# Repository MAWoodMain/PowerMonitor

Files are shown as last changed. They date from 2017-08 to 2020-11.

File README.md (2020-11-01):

# PowerMonitor
This is a tool for monitoring household electrical power using multi-channel  clamp based hardware, it defaults to monitoring at a 1 second rate. Although it could run faster than this, it hasn't been tested at higher rates.

The orignal concept was to make energy disagregation easier by providing a capability to monitor the main meter feed to a house, and all of the individual circuits. So the hardware allows for one 100 Amp current clamp (with burden resitor on the board), and 8 other clamps without burden resistors for use with lower power clamps which include thier own burden resistors. Currently only the main meter feed (whole house) is being used, but the other circuits do operate (with appropriate configuration), but haven't been exaustively tested. 

## Software
The software has been developed in Java. Java language level 8 is used because of limited availability of a Java run time for the RPI Zero W above 8. Originally the software was developed to use an API interface for updating a database, but all of the more recent deveopment has focused on using an MQTT interface with JSON encoded messages. This is to fit in with the MING stack (MQTT, Influx, Node-RED, Grafana) for transmitting, storing processing and displaying the data.

## Firmware
The firmware written in C is based on that produced by the [EmonPi project](https://github.com/openenergymonitor/emonpi) but has been modified to read multiple circuits, and operates with a shorter cycle time to help with disgregation. As such it needs a A/C to A/C transofrmer to provide a waveform plus a power supply for the RPi

## Hardware
The hardware was developed by [Matt Wood](https://github.com/MAWoodMain) at an early stage of his experimentation with hardware, from my perspective it does a fine job, but he now sees ways it can be done better. Future improvements may include noise reduction and higher accuracy.

## Metrics
The following Metrics are collected
### Basic Metrics
  1. Voltage (Volts)
  2. Current (Amps)
### Power Metrics (calculated from basic metrics)
  1. Real Power (Watts)
  2. Apparent Power (VA - Volt Amps)
  3. Reactive Power (VAR - Volt Amps Reactive)
  4. Power Factor (Real / Apparent)
### Energy Metrics (calculated from power metrics)
  1. Energy over accumulation interval (Watt Hours)
  2. Cumulative Energy today (Kilowatt Hours)

## Current Release
The current release 0.3-alpha has the following improvements over the last release
### Code Structure
  * The code has been fundamentally restructured to allow for commands to alter data, enums have been replaced by classes.
  * The command processor and associated supporting classes have been added
  * All commands and responses are now sent using JSON rather than arbitary text
  * Much of the code has been restructured as a result of the above items
### Commands via MQTT
A number of get and set commands and their responses have been implemented via JSON over MQTT
the full list off the commands and their syntax can be found here [Commands](https://github.com/gjwo/PowerMonitor/blob/master/Commands.md)
. If there are errors in the commands an error response will be sent in most cases.
### Transmitted Data structure changes
The data sent via streaming or polling is now structured as json object reflecting java data structures shown below
```$xslt
    String time;
    String device;
    int channel;
    String circuitTag;
    Circuit<type>Readings readings; for <type> see below
Power Readings
    Double voltage;
    Double current;
    Double realPower;
    Double reactivePower;
    Double apparentPower;
    Double powerFactor;
Energy Readings
    Double energy;
    Double cumulativeEnergy; 
```
Each data structure transmitted now contains the name of the device and circuit, to make interpretation easier in receiving systems such as NodeRED.
### Streaming or Polling suported
By default the PowerMonitor will still stream data, but it is possible to turn streaming off,
using the Circuit publishPower & Publish Energy settings, setting these false will stop
streaming for that type of data.
NB the data is still collected internally and be be retrieved via the get powerdata and 
get energydata commands i.e. polling. These commands currently return the latest data only.

It is also possible to not monitor circuits at at all by setting the monitor setting 
to false for the circuit.

##Future Plans
I am open to suggestions, but things I am thinking about include:
  * Retrieval of data for a specific period
  * Making some data persistant (energy for example)
  * Logging improvements including using a more formal logging system and being able to turn
   logging on for a specific level remotely, and also log to file locally.
   
The focus may shift to doing things with the data collected for the next little while, as this
release does most of what I need it to.

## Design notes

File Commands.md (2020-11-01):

# PowerMonitor Commands
## Command line parameters
Some basic configuration can be set via the command line, some of these are required for communication so can only be supplied by this method.
  1. -h to get help
  2. -m <ip address> to set the MQQT server address
  3. -c <client name> to set a client name (also used in MQTT topics)
  4. -i <number of minutes> to set the accumulation interval for energy collection and output
The parameters would normally be set in the PowerMonitor.service file, as the PowerMonitor should be run as a service. see example below.
```
ExecStart=/bin/sh -c "exec sudo java -jar /opt/PowerMonitor/Software/deployment/PowerMonitor.jar -m 10.0.128.2 -i 5 -c PMon10"
```
## Basics
PowerMonitor can receive commands via MQTT, the commands need to be sent in JSON format on the topic /emon/device name/cmnd. Replies will be sent on the topic /emon/device name/response. NB currently data changes are not persisent through restarts of the service.
NB All fields must be completed, as "" if not required.
The command structure is:
```
  {
    "command":"<command>",
    "subject":"<subject>",
    "key":"<key>",
    "data":"<data>"
  } 
```
## Commands
The following commands are available -
  1. Get - gets some data from the PowerMonitor
  2. Set - Sets some data on the PowerMonitor
## Subjects
The following subects are available
  1. circuit        - parameters for circuits
  2. clamp          - parameters for current clamps
  3. metricreading  - A metric reading
  4. powerdata      - Multiple basic and power latest readings for a circuit
  5. energydata     - Latest energy and cumulative energy readings for a circuit
## Keys
The following key values are permitted
  1. for a circuit: the channel number of the circuit as a string, the circuit tag (the name with spaces replaced by underscores)
  2. for a clamp: the clamp name
  3. for a metric reading: the same keys as for circuit (but see data section)
  4. for powerdata: the same keys as for circuit
  5. for energydata: the same keys as a circuit
## Data
### For Get Commands
Only get metric <circuit> optionally requires information in the data field, if "" is specified the "Amps" will be used. possible values are : volts, milli_volts, amps, milli_amps, watt_hours, kilowatt_hours, va, var, kilowatt, powerfactor.
### For Set Commands
For set commands a pair of values are required within the data string
#### Set Clamp <key>
  * "offset <floating point number (up to double precision)>" - added to the reading to correct offset errors
  * "scale <floating point number (up to double precision)>"  - multiplied by the reading to correct scaling errors
#### Set Circuit <key>
  * "displayname <new display name (may contain spaces)" - essentially renaming the circuit
  * "clampname <clampname>" - changing the type of clamp associated with the circuit
  * "monitor <true or false>" - changing if data is collected for the circuit anything that is not true is considered as false
  * "publishpower <true or false>" - if not true basic & power data is collected without being streamed
  * "publishenergy <true or false>" - if not true energy data is collected without being streamed
## Responses
Successful Get and Set commands will respond with the current value of the subject identified.
## Errors
Errors will result in a reponse record wich has the following fields
  1. command - the full command that generated the response.
  2. result - normally "Error", could be "Info" if the request was valid but can't be satisfied
  3. detail - normally further information about the result
  4. location - where the response was generated from (normally a method name)

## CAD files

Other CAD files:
Firmware/powermonitor.stp
Firmware/powermonitor_Programmer/powermonitor_STVP.stp

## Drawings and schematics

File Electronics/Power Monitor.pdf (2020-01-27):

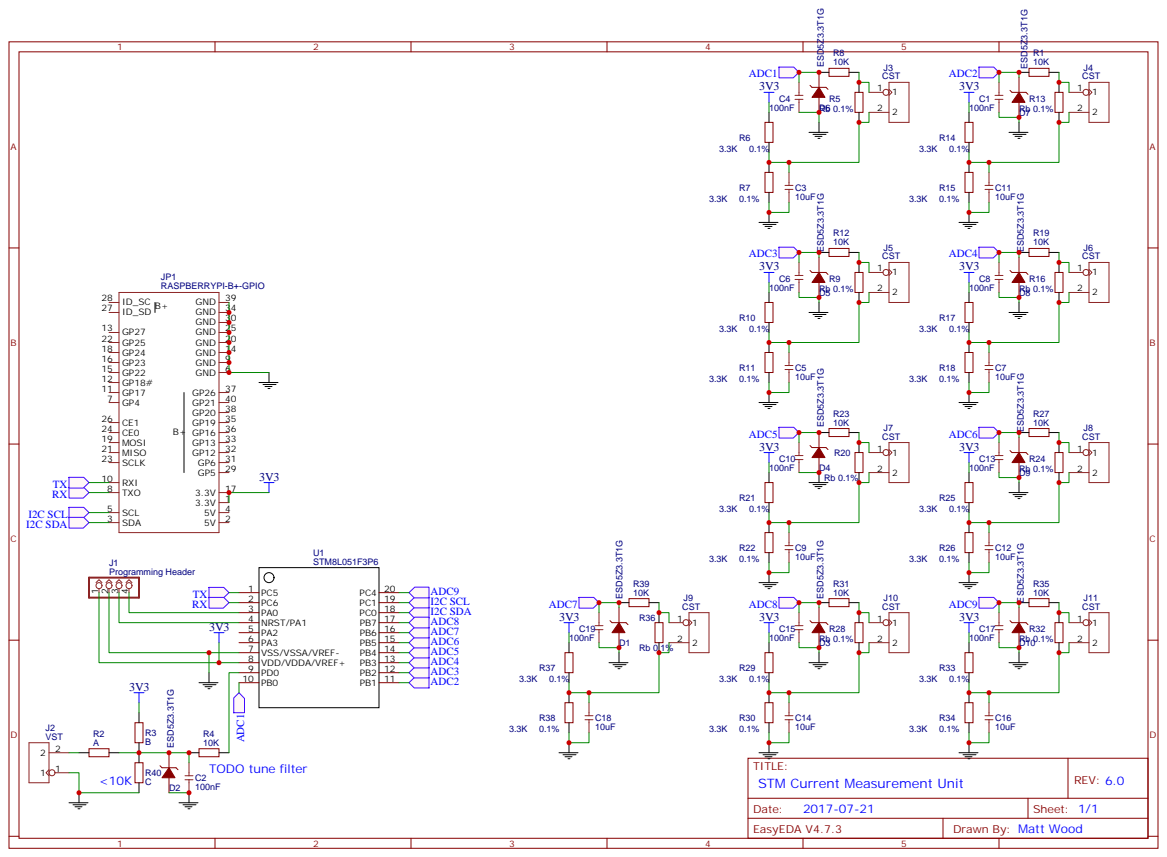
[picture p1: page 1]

TITLE:
STM Current Measurement Unit

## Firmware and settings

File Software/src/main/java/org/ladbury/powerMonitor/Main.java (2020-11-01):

package org.ladbury.powerMonitor;

import com.beust.jcommander.JCommander;
import org.ladbury.powerMonitor.PMhealth.MemoryMonitor;
import org.ladbury.powerMonitor.circuits.*;
import org.ladbury.powerMonitor.control.CommandProcessor;
import org.ladbury.powerMonitor.currentClamps.Clamps;
import org.ladbury.powerMonitor.publishers.MQTTHandler;
import org.ladbury.powerMonitor.publishers.PMLogger;
import org.eclipse.paho.client.mqttv3.MqttException;
import java.util.concurrent.LinkedBlockingQueue;
import java.util.logging.Level;

public class Main
{
    private static MQTTHandler mqttHandler;
    private static final LinkedBlockingQueue<String> commandQ = new LinkedBlockingQueue<>();
    private static final Circuits circuits= new Circuits();
    private static final Clamps clamps = new Clamps();
    private static CircuitCollector circuitCollector;
    private static MemoryMonitor memoryMonitor;
    private static PMLogger logger;
    private static Level loggingLevel;

    // Getters
    public static MemoryMonitor getMemoryMonitor(){return memoryMonitor;}
    public static MQTTHandler getMqttHandler()
    {
        return mqttHandler;
    }
    public static LinkedBlockingQueue<String> getCommandQ()
    {
        return commandQ;
    }
    public static Circuits getCircuits(){return circuits;}
    public static Clamps getClamps(){return clamps;}
    public static CircuitCollector getCircuitCollector() {return circuitCollector;}
    public static PMLogger getLogger() {return logger;}

    @SuppressWarnings("SpellCheckingInspection")
    private static void help()
    {
        System.out.println( "Energy Monitor Help");
        System.out.println();
        System.out.println(" The following parameters may be entered on the command line:");
        System.out.println("--mqqtserver or -m  This switch must be followed by an IP address for the MQTT server");
        System.out.println("--ClientName or -c  This switch must be followed by a client name for this monitor");
        System.out.println("--interval or -i  This switch must be followed by an integer number of minutes over which time energy is to be accumulated");
        System.out.println("--LoggingLevel or -l  This switch must be followed by a valid logging level string such as   fine, config, info, warning, severe");
        System.out.println( "--help or -h  This switch causes this help to be displayed and the program terminates" );
        System.out.println( "Any or all of the parameters may be omitted, in which case hard coded values will be used (see code)");
    }

    public static void main(String[] argv)
    {
        //Initialise variables
        int energyAccumulationIntervalMins = 5; // Minutes
        long samplingIntervalMilliSeconds = 1000; // Milliseconds
        logger = new PMLogger(Level.INFO);
        //Handle arguments
        Args args = new Args();
        JCommander.newBuilder()
                .addObject(args)
                .build()
                .parse(argv);

        if (args.isHelp())
        {
            help();
            System.exit(0);
        }
        if (args.getAccumulationInterval()>0){energyAccumulationIntervalMins = args.getAccumulationInterval();}
        try {
            //logger.add("Enabling MQTT", Level.INFO, Main.class.getName());
            mqttHandler = new MQTTHandler(args.getMqttServer(), args.getClientName(), getCommandQ());
        } catch (MqttException e) {
            MQTTHandler.handleMQTTException(e);
            System.exit(9);
        }
        if (args.getLoggingLevelStr()!=null)
        {
            Level l;
            try {
                l = Level.parse(args.getLoggingLevelStr().toUpperCase());
            } catch (IllegalArgumentException e) {
                System.out.println("illegal logging level");
                l = Level.INFO;
                System.exit(10);
            }
            logger.setLoggingLevel(l);
        }
        // set up & start support processes
        logger.start();
        logger.add("Enabled Logger", Level.INFO,Main.class.getName());
        logger.add("Enabling CommandProcessor", Level.FINE, Main.class.getName());
        memoryMonitor = new MemoryMonitor(5);
        logger.add("#"+getMemoryMonitor().getTotalHeapSize()+"#Initial heap size", Level.INFO, Main.class.getName());
        logger.add("#"+getMemoryMonitor().getCurrentHeapSize()+"#current heap size start of main", Level.INFO,Main.class.getName());
        CommandProcessor commandProcessor = new CommandProcessor(getCommandQ());
        commandProcessor.start();

        logger.add("Enabling CircuitCollector", Level.FINE, Main.class.getName());
        circuitCollector = new CircuitCollector(samplingIntervalMilliSeconds, energyAccumulationIntervalMins);
        //circuits has initial values set to monitor the whole house but no other circuits
        //additional circuits can be set to monitor via the mqtt commands
        for( Circuit circuit : circuits.getCircuits()){
            if (circuit.isMonitored())
                circuitCollector.enableCollection(circuit);
                circuit.setPublishPower(true);
                circuit.setPublishEnergy(true);
        }
        circuitCollector.start();
        logger.add("#"+getMemoryMonitor().getCurrentHeapSize()+"#Heap used after Main", Level.INFO, Main.class.getName());
        Runtime.getRuntime().gc();
    }
}

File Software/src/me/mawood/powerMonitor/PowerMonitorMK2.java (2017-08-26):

package me.mawood.powerMonitor;

import com.pi4j.io.serial.*;
import me.mawood.powerMonitor.metrics.sources.CurrentClamp;

import java.io.IOException;
import java.io.UnsupportedEncodingException;
import java.util.ArrayList;
import java.util.Arrays;
import java.util.Collection;
import java.util.Iterator;

public class PowerMonitorMK2 extends Thread implements SerialDataEventListener, PowerMonitor
{
    private static final byte[] START_SEQUENCE;
    private static final int PACKET_LENGTH;
    private final Collection<Byte> incomingBytes;
    private final Collection<Byte> bytes;
    private final Collection<PowerMonitorPacket> packets;

    private final Collection<PacketEventListener> listeners;

    private long extractionPeriod;

    private final Serial serial;


    static
    {
        final char[] startString = "PM_START".toCharArray();
        START_SEQUENCE = new byte[startString.length];
        for (int i = 0; i < startString.length; i++)
            START_SEQUENCE[i] = (byte)startString[i];
        PACKET_LENGTH = START_SEQUENCE.length+10+1+9*2*10;
    }


    public PowerMonitorMK2() throws IOException, InterruptedException
    {
        this.extractionPeriod = 3000;
        this.bytes = new ArrayList<>();
        this.incomingBytes = new ArrayList<>();
        this.packets = new ArrayList<>();
        this.listeners = new ArrayList<>();
        this.serial = SerialFactory.createInstance();

        SerialConfig config = new SerialConfig();
        config.device(SerialPort.getDefaultPort())
                .baud(Baud._230400)
                .dataBits(DataBits._8)
                .stopBits(StopBits._1)
                .parity(Parity.NONE)
                .flowControl(FlowControl.NONE);
        serial.addListener(this);
        serial.open(config);

        this.start();
    }
    @Override
    public void run()
    {
        long time;
        Collection<PowerMonitorPacket> newPackets;
        super.run();
        while(!Thread.interrupted())
        {
            time = System.currentTimeMillis();
            if(incomingBytes.size() > 0)
            {
                synchronized (incomingBytes)
                {
                    bytes.addAll(incomingBytes);
                    incomingBytes.clear();
                }
                newPackets = new ArrayList<>();
                for(byte[] packet:extractPackets(bytes))
                {
                    try
                    {
                        newPackets.add(new PowerMonitorPacket(packet));
                    } catch (IllegalArgumentException | UnsupportedEncodingException ignored) {
                        System.out.println(ignored);
                    }
                }
                packets.addAll(newPackets);
                alertPacketListeners(newPackets);

            }
            while(time + extractionPeriod > System.currentTimeMillis())
            {
                // wait half the remaining time
                try
                {
                    Thread.sleep(Math.max(0,((time + extractionPeriod)-System.currentTimeMillis())/2));
                } catch (InterruptedException ignored) {}
            }
        }
    }
    private void alertPacketListeners(Collection<PowerMonitorPacket> newPackets)
    {
        for(PacketEventListener listener:listeners) listener.handleNewPackets(newPackets);
    }

    private Collection<byte[]> extractPackets(Collection<Byte> rawData)
    {
        Iterator<Byte> it = rawData.iterator();
        byte item;
        int tracker = 0;
        boolean found = false;
        byte[] packet = new byte[PACKET_LENGTH];
        Collection<byte[]> packets = new ArrayList<>();
        while(it.hasNext())
        {
            item = it.next();
            if(found)
            {
                if (tracker >= PACKET_LENGTH)
                {
                    // reached end of packet
                    tracker = 0;
                    found = false;
                    packets.add(packet.clone());
                } else
                {
                    packet[tracker] = item;
                    // remove consumed characters
                    it.remove();
                    tracker++;
                }
            } else
            {
                if(tracker >= START_SEQUENCE.length)
                {
                    // end of start sequence start of data
                    found = true;
                    tracker = 0;
                    packet[tracker] = item;
                    tracker++;
                    // remove consumed characters
                    it.remove();
                } else if(item == START_SEQUENCE[tracker])
                {
                    tracker++;
                    it.remove();
                }
            }

        }
        return packets;
    }

    public void addPacketEventListener(PacketEventListener listener)
    {
        this.listeners.add(listener);
    }

    @Override
    public void dataReceived(SerialDataEvent serialDataEvent)
    {
        try
        {
            for(byte b:serialDataEvent.getBytes()) incomingBytes.add(b);
        } catch (IOException ignored) {}
    }

    public void close() throws IOException
    {
        this.interrupt();
        serial.close();
    }

    public static void main(String[] args) throws IOException, InterruptedException
    {
        PowerMonitorMK2 powerMonitor = new PowerMonitorMK2();
        CurrentClamp clamp0 = new CurrentClamp((byte)0,CurrentClampConfig.SCT013_5A1V,powerMonitor);
        CurrentClamp clamp1 = new CurrentClamp((byte)1,CurrentClampConfig.SCT013_5A1V,powerMonitor);
        powerMonitor.addPacketEventListener(e -> {
            System.out.println(clamp0);
            System.out.println(clamp1);
        });
        Thread.sleep(60000);
        powerMonitor.close();
        System.exit(1);
    }
}

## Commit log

2017-08-19 Created test code to print bytes received.
2017-08-19 Added Firmware files to VCS
    [powermonitor_STVP.stp]
2017-08-19 Added firmware, RTC working UART WIP
    [powermonitor.stp, powermonitor_STVP.stp]
2017-08-19 Added MQTT Paho to repo
    [powermonitor.stp]
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2017-08-20 Firmware ADC operational, RTC not ticking, serial operational
2017-08-20 Added scalling by max current of clamp
2017-08-20 Finished firmware V1 awaiting testing when voltage sense circuit is ready
    [powermonitor.stp]
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2017-08-21 Restructure, move serial into STM8PowerMonitor, add CurrentClamp enum
2017-08-21 Restructure, handle adc channels and cycle channels then metric
2017-08-21 Added more firmware files
    [powermonitor.stp]
2017-08-22 MetricsBuffer.print, restructure to GetScaledMetrics, tidy up
2017-08-23 Added PowerMonitor interface and used to make pluggable, used noChannels
2017-08-23 Add getAndResetRawMetricsBuffer() to prevent averaging forever
    [STM8PowerMonitor.java]
2017-08-25 Fixed firmware to send float vals as strings, made new packet lexer and parser, currently working -Matt W
    [powermonitor.stp, powermonitor_STVP.stp]
2017-08-26 Restructured data gathering and storage, moved clamp compensation to pi, working.
2017-08-26 Adjusted magic voltage constants and implemented real power measurement
2017-08-26 Calibrated 5A clamp and moved value calibration into config
2017-08-26 Added apparent power, reactive power and power factor calculations
2017-08-26 Fixed firmware to calculate power in parallel
    [STM8PacketCollector.java, adc.c, calcvi.c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]
2017-08-26 Debugging at testing with 20 clamp with 6A load
    [powermonitor.stp]
2017-08-27 Fixed circular array list iterator, tested pmc
    [Main.java]
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2017-08-27 Fixed MQTT, testing using linux MQTT client.
    [Main.java]
2017-08-29 Corrected format and content of MQTT Topics and messages
    [Main.java]
2017-08-30 Working with emoncms, 1 value per circuit
2017-08-31 Tidy up and add noise filter to metrics
    [Main.java]
2017-09-04 comment out debug printing of sent message
2017-09-04 Remove PowerDataSubscriber, move pdp.start() to main
2017-09-13 Remove exception print on no data
2017-09-23 Added tags to circuits, more refactoring
2017-09-23 Discover or create DB devices in contructor
2017-10-14 Fixed crash on channel missing data
    [Main.java]
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2017-12-06 removed redundant class path switch in service, added debug print in packet collector
2020-01-21 comment out database publisher, uncomment and correct mqqt publisher
    [Main.java]
2020-01-24 All readings for a circuit bundled into a JSON object
2020-01-24 Removed redundant strings from voltage and updated jar
2020-01-24 Enable a second circuit and updated jar
2020-01-25 Update calcvi.c
    Fixed variable naming
    [calcvi.c]
2020-01-25 Fixed errors and recompiled
    [calcvi.c]
2020-01-25 Change calibration for 20A clamp
2020-01-25 Remove all calibration form 20A clamp and update jar
2020-01-25 Round metrics values to 6 decimals, add voltage to all MQTT messages & Update Jar
2020-01-25 Add missing comma to Voltage JSON & Update Jar
2020-01-25 Also add rounding to PowerFactor calculation
2020-01-26 Mechanism to enable and disable circuit data collection added in preparation for control by MQQT command, old mechanisms removed
2020-01-26 Start MQTT before circuit monitoring for logging
2020-01-26 Corrected json, further order changes, update jar
    [Main.java]
2020-01-27 separate Logging, CommandProcessor & PowerDataMQTTPublisher
2020-01-27 Added Schematic to repo
2020-01-27 Re shuffled channels to match silkscreen.
2020-01-28 Tidy up queues, add circuit selection, add status messages
2020-01-28 attempt to fix null pointer exception by changing order processes start, update jar
    [Main.java]
2020-01-28 Added CircuitCollector (needs removing from mqtt still)
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2020-01-28 Removed circuit elements from publisher and refactored
2020-01-28 MQTT reengineered without thread, lots of refactoring
2020-01-31 Initial completetion of PowerMetricCalculator rewrite
2020-01-31 Remove energy cases, tidy case statements,
2020-01-31 Remove space from PowerFactor name,Update Jar
2020-02-01 Energy store completed with buckets & syncronized updates
2020-02-02 Add bracket sarround interger division
2020-02-02 tidy up and add debug print in energy store, updated jar
2020-02-02 average when updating bucket, updated jar
2020-02-02 Stop storing energy for disabled circuits, updated jar
2020-02-02 pass map not circuit count, change logging, remove diagnostic print, updated jar
2020-02-03 Revert "Stop storing energy for disabled circuits, updated jar"
    This reverts commit eaa5a9758d9c08d5610518ad79b8033a9b95b197.
    # Conflicts:
    # Software/src/me/mawood/powerMonitor/Main.java
    # Software/src/me/mawood/powerMonitor/circuits/EnergyStore.java
    [Main.java]
2020-02-03 Revert "pass map not circuit count, change logging, remove diagnostic print, updated jar"
    This reverts commit 874b8cb9
    [Main.java]
2020-02-03 Revert powerfactor changes as they cause exception, update Jar
2020-02-03 First version of CircuitEnergyStore
2020-02-03 Replace EnergyStore with CircuitEnergyStore, update Jar
    [Main.java]
2020-02-04 clarify energy calculation (buckets not cumulative), update jar
2020-02-05 replay Missing main changes to remove Energystore
    [Main.java]
2020-02-14 Tidy up build Pi4j 1.2 instead of snapshot, Add parameter handling, change MQQT handler to parameterise address of broker
    [Main.java]
2020-02-19 update circuit data structures
2020-02-19 Update code to use circuits classes and remove redundant items
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2020-02-20 Remove CurrentClampConfig and replace with updatable clamps
    [Main.java]
2020-02-20 Command strucruture revised, CircuitData added
2020-02-20 get circuit command implemented
2020-02-20 get clamp command implemented, topic changed in service, gson added, jar updated
2020-02-21 Clamp working circuit add more logs, update jar
2020-02-21 fix channel numbers in Circuits, update jar
2020-02-21 add get channel bt tag to get circuit, update jar
2020-02-21 get circuit data implemented, update jar
2020-02-21 replace array with arraylist in circuits, update jar
    [Main.java]
2020-02-22 tidy up, correct PowerFactor error, update jar
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2020-02-25 Major rewrite of CircuitCollector to split collection and publishing and introdution or refacroing of types for json conversion, update jar
2020-02-25 control of publishing added to circuits, update jar
2020-02-25 improve error responses, initialise circuitEnergyData in collector, update jar
2020-02-26 Add device to power & energy data to make NodeRED code easier, tidy up circuits reduce access from public in circuits, update Jar
2020-02-26 correct device name to tag, change field order, update Jar
2020-02-26 change monitor name in service to live device
2020-02-26 Update documentation to match current state of code.
2020-02-27 Major restructuring to move all circuit initialisation & processing functionality from main to CircuitCollector. Update Jar
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2020-02-28 CircuitCollector use channel number rather than circuit as map keys and remove duplicate flags by accessing Circuits, Update Jar
2020-02-28 remove code duplication, reset bucket schedule (missing call), Update Jar
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2020-02-29 Tidy up clamps back to pmon10, change 100A clamp scale, update Jar
2020-04-13 Add exception handling to CircuitEnergyStore, following loss of scheduled thread after 4 weeks. Update jar
2020-05-23 Add memory tracing to main and bucket filler, Update jar
2020-05-23 Add memory tracing to main and bucket filler (fix), Update jar
    [Main.java]
2020-05-23 Add memory tracing to main and bucket filler (fix2), Update jar
    [Main.java]
2020-06-11 correct initialisation error, update Jar
    [Main.java]
2020-09-05 Add exception handling to catch memory error, update Jar
    [STM8PacketCollector.java]
